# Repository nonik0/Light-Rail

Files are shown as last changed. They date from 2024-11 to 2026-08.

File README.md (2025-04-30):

# Light Rail

## Overview & Acknowledgements

GIF animation of the basic hardware demo

Light Rail is a minimalist, interactive PCB game that simulates trains traveling along tracks, picking up and delivering cargo from platforms. The track is composed of yellow LEDs arranged in lines, which illuminate sequentially to create the effect of trains moving along the tracks. Next to each of the eight forks and crosses in the track is a button to switch its state. The board also has a three-character seven-segment display for showing the game status and/or score and four more buttons underneath the track for gameplay control. Light Rail can be powered with two LIR2032 batteries or via USB.

I also want to acknowledge and thank [PCBWay](https://www.pcbway.com/) for their generous support of this project! Even before I had the initial idea, PCBWay had already reached out to me asking if I would like to collaborate on my next project. However, I didn't actually see the email until I started looking into how I wanted to manufacture prototypes for Light Rail. Just getting the email and seeing that others were liking my older projects gave me a big motivation boost to continue with this project, be creative, and make something of my own. Overall, my experience with PCBWay was great and I would definitely recommend checking them out for your own projects!

For more details about my design goals, process, and ordering and production experience with PCBWay, please see my full [project writeup](https://altonimb.us/light-rail/)!

### Work Left
- first working game prototype
- further game ideas and testing
- investigate CR2032 batteries in series

## Hardware
The hardware is designed in KiCad 8.0 and all design files are included in the [hardware/kicad8.0](hardware/kicad8.0) directory.

The main hardware components are:
- [ATMega32u4](https://www.microchip.com/en-us/product/atmega32u4) 8-bit MCU
- [IS31FL3731](https://www.lumissil.com/applications/industrial/appliance/major-appliances/range-hood/is31fl3731) matrix LED driver (charliplexing)
- [AS1115](https://ams-osram.com/products/drivers/led-drivers/ams-as1115-led-driver-ic) seven-segment LED display driver
- [KCSC02-105](https://www.kingbright.com/attachments/file/psearch/000/00/00/KCSC02-105(Ver.12A).pdf) seven-segment LED display
- [MIC5219](https://ww1.microchip.com/downloads/en/DeviceDoc/MIC5219-500mA-Peak-Output-LDO-Regulator-DS20006021A.pdf) 3.3V LDS Regulator
- Yellow "track" and red "platform" LEDs, 144 total

See the [Bill of Material (BoM)](hardware/documents/Light_Rail_BOM.xlsx) for complete list of components used and my [project writeup](WRITEUP.md) for more details.

## Firmware

The firmware initially started as a C++/PlatformIO project, which can be found in the [firmware/cpp](firmware/cpp) directory. Before I actually received the inital prototype boards I decided to pivot and write everything in Rust, which can be found in the [firmware/rust](firmware/rust) directory. As part of the effort to get back to where I left off with the C++ firmware, I did the following:
- Wrote a new [AS1115 driver](https://github.com/nonik0/as1115) (TODO: finish and polish design before publishing to crates.io)
- Wrote new tone library for avr-hal (TODO: integrate into avr-hal and open PR)
- Updated existing fork of [IS31FL3731](https://github.com/nonik0/is31fl3731) driver to latest embedded-hal with other minor additions

TODO: basic overview of game design and firmware components (in second writeup?)

## Images

#### Prototype
<p align="center" width="100%">
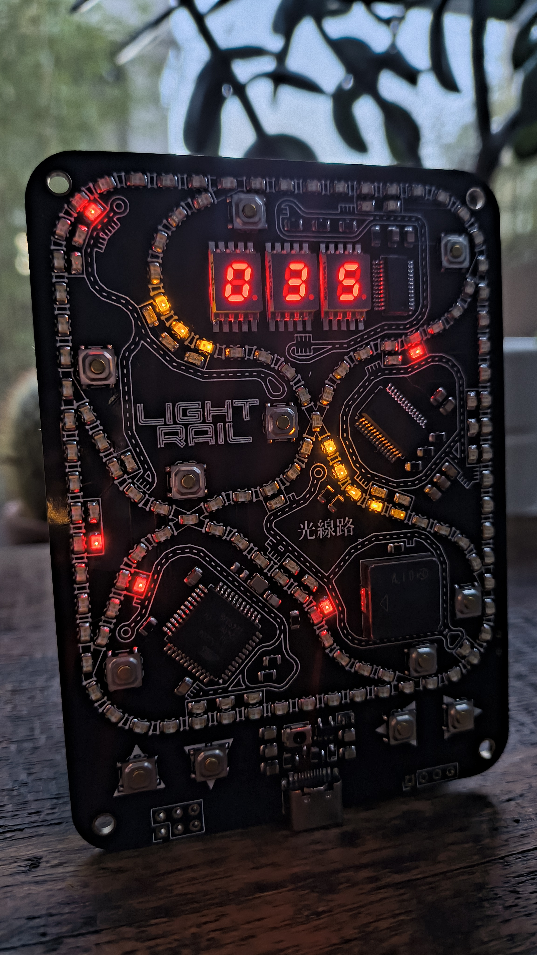
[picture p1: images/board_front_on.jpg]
  
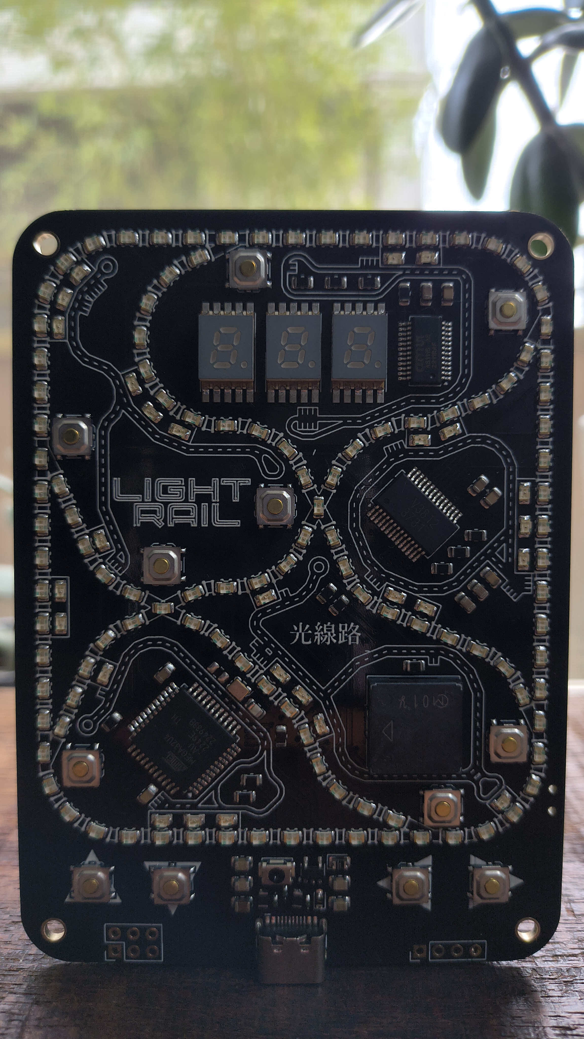
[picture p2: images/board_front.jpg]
  
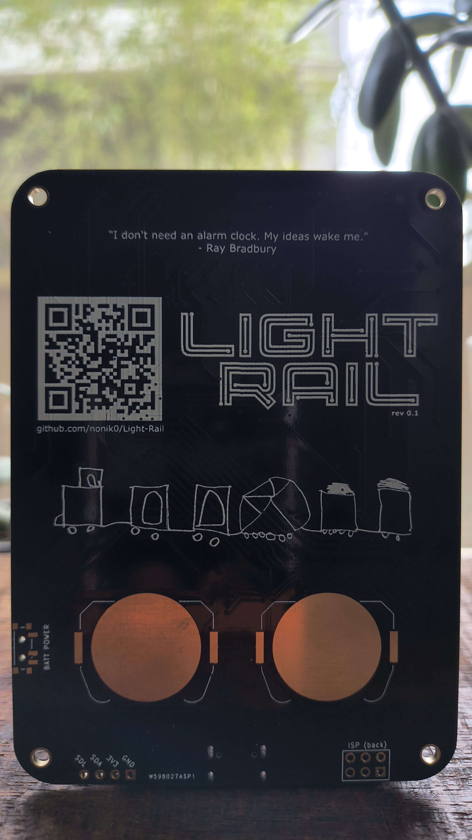
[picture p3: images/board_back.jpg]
  
</p>

#### Schematic
<p align="center" width="100%">
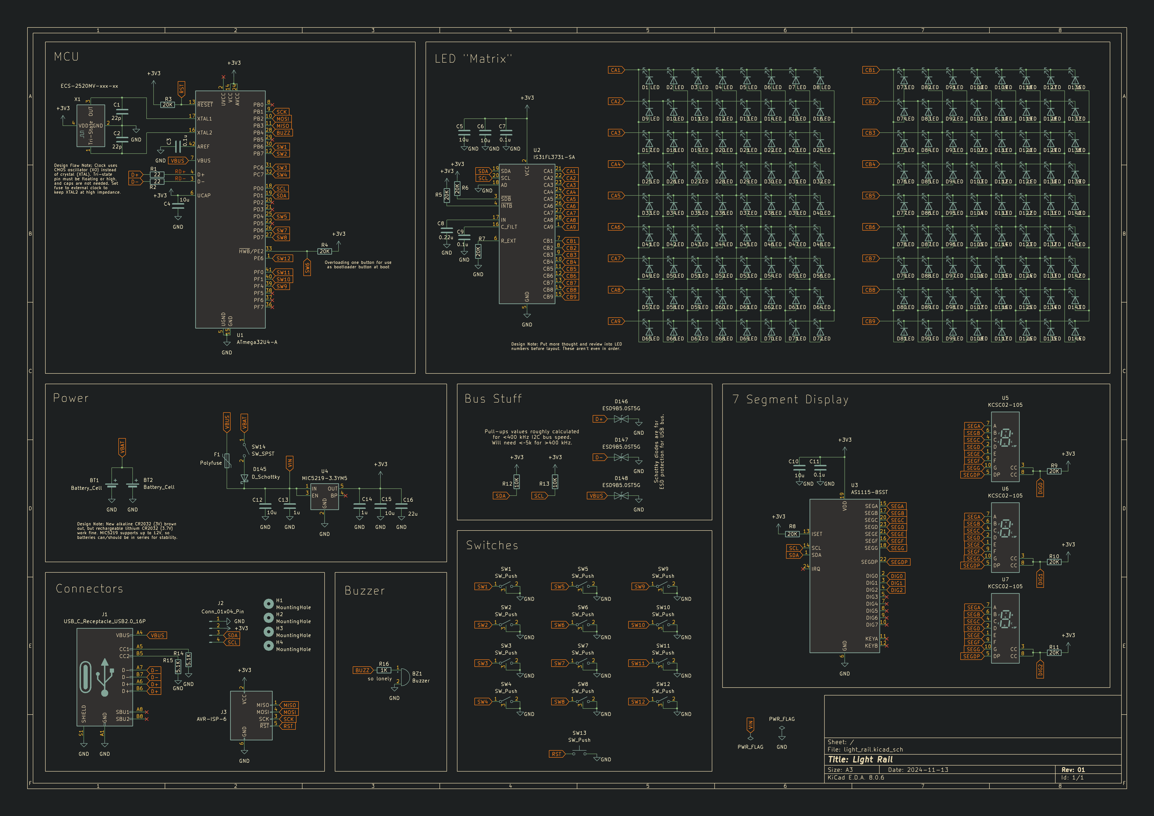
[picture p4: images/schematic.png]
  
</p>

#### PCB Layout
<p align="center" width="100%">
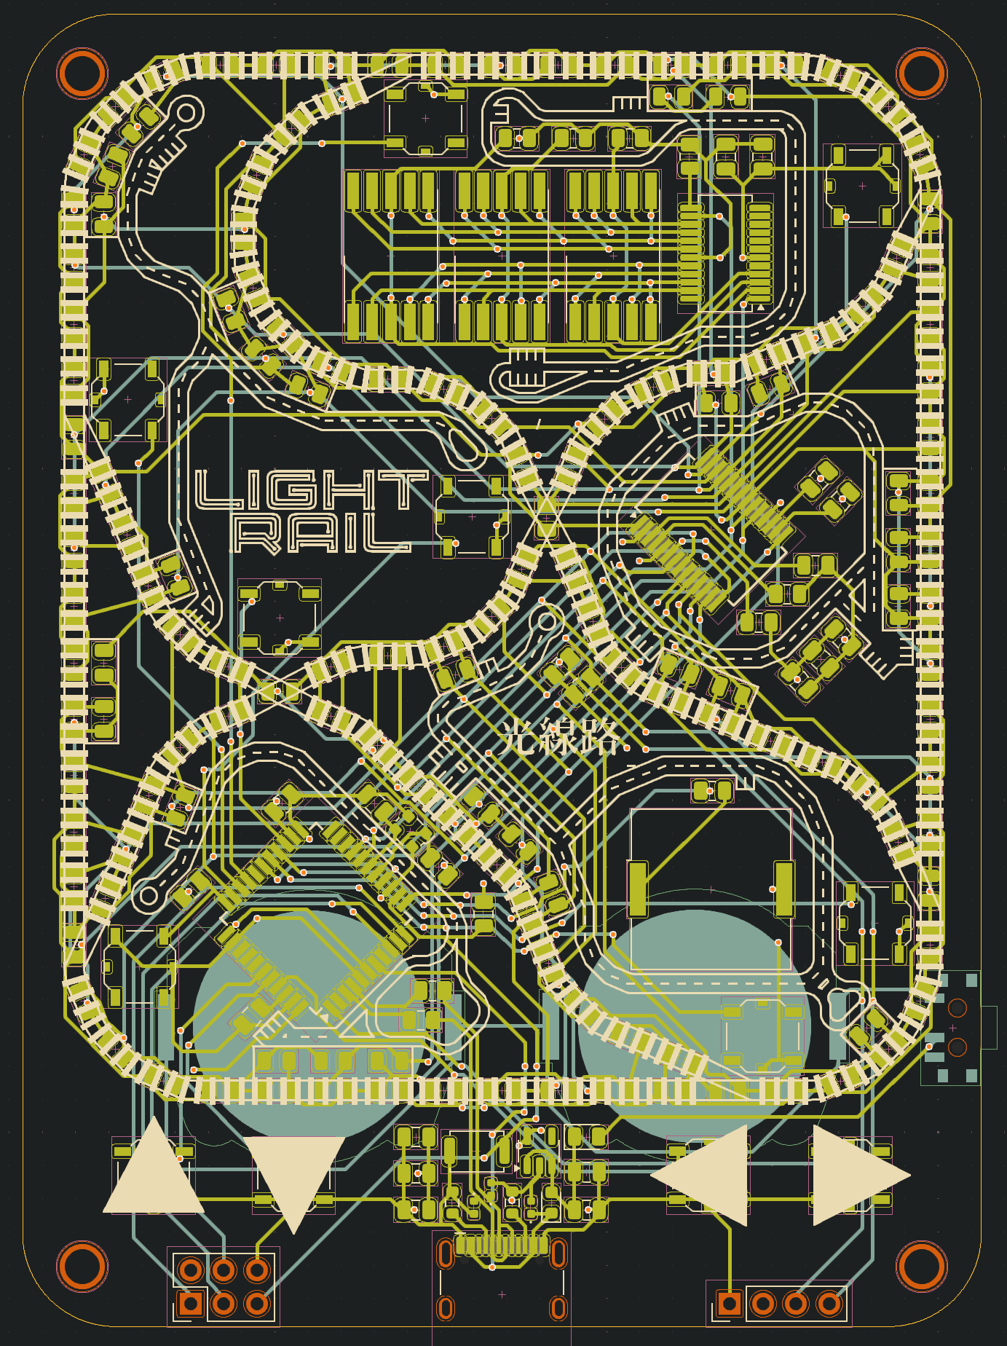
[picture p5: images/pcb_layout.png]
  
</p>

#### Render
<p align="center" width="100%">
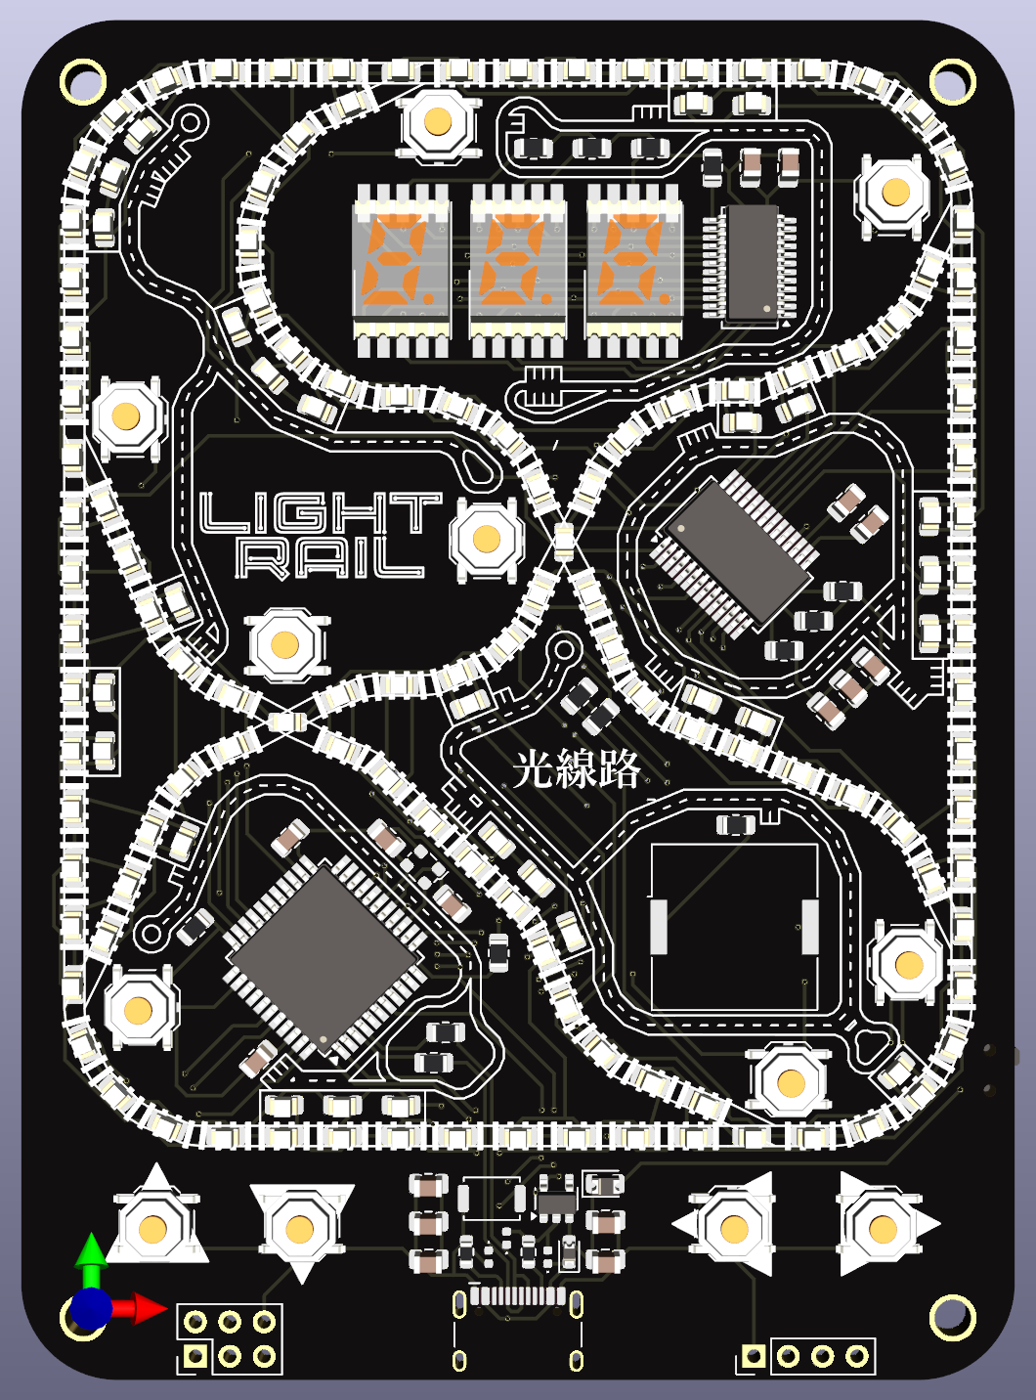
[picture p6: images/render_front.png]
  
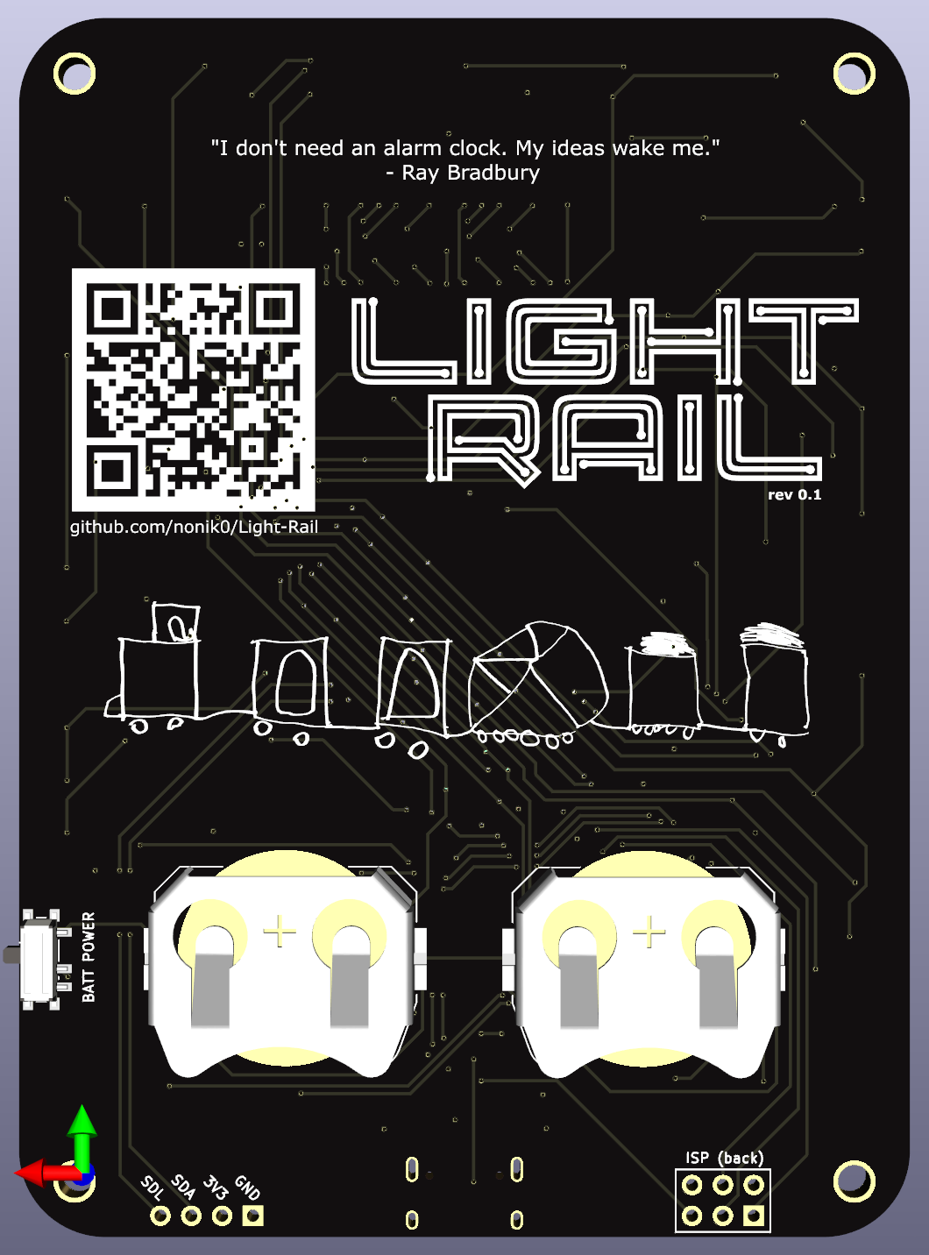
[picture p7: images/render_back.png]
  
</p>

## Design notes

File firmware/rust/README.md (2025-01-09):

light-rail
==========

Rust project for the _Arduino Leonardo_.

## Build Instructions
1. Install prerequisites as described in the [`avr-hal` README] (`avr-gcc`, `avr-libc`, `avrdude`, [`ravedude`]).

2. Run `cargo build` to build the firmware.

3. Run `cargo run` to flash the firmware to a connected board.  If `ravedude`
   fails to detect your board, check its documentation at
   <https://crates.io/crates/ravedude>.

4. `ravedude` will open a console session after flashing where you can interact
   with the UART console of your board.

[`avr-hal` README]: https://github.com/Rahix/avr-hal#readme
[`ravedude`]: https://crates.io/crates/ravedude

## License
Licensed under either of

 - Apache License, Version 2.0
   ([LICENSE-APACHE](LICENSE-APACHE) or <http://www.apache.org/licenses/LICENSE-2.0>)
 - MIT license
   ([LICENSE-MIT](LICENSE-MIT) or <http://opensource.org/licenses/MIT>)

at your option.

## Contribution
Unless you explicitly state otherwise, any contribution intentionally submitted
for inclusion in the work by you, as defined in the Apache-2.0 license, shall
be dual licensed as above, without any additional terms or conditions.

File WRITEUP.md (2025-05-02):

Moved [here](https://altonimb.us/light-rail/).

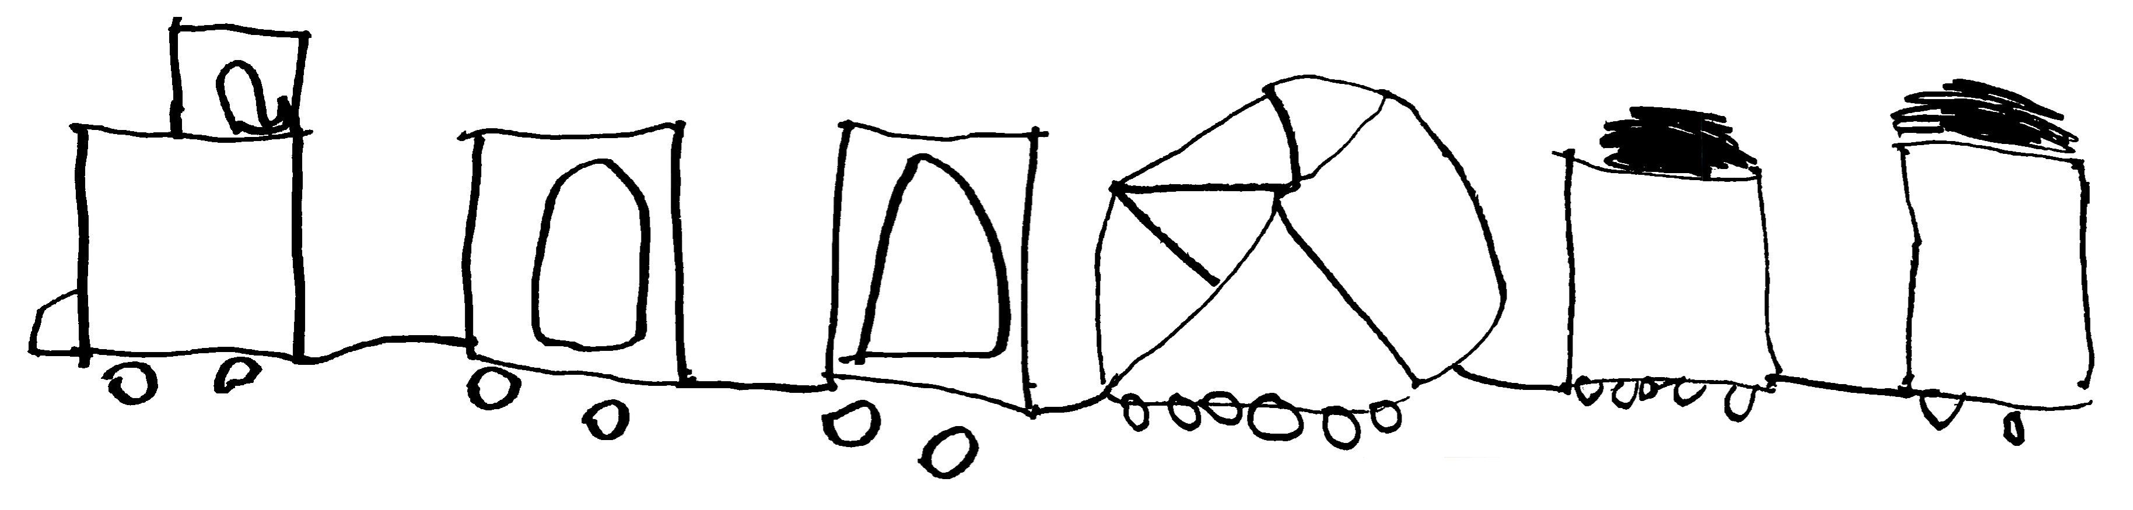
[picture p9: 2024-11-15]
images/train_drawing_long.png

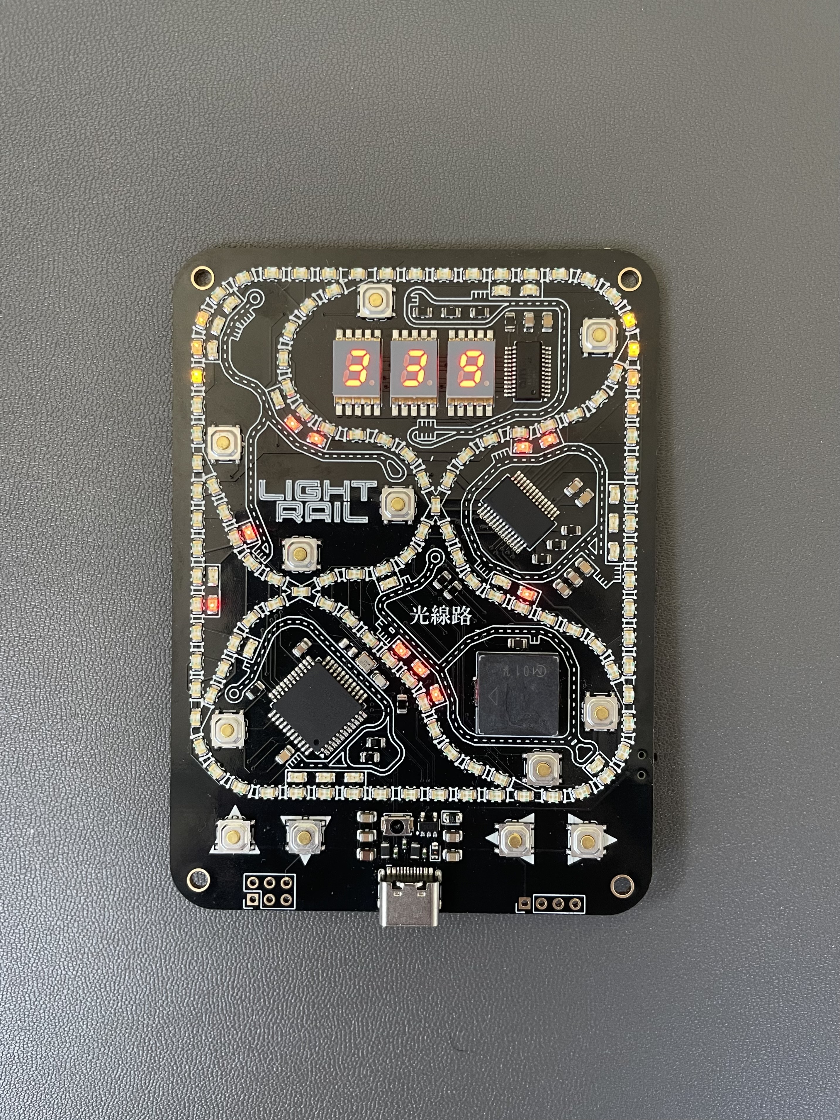
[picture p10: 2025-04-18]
images/board_front_2.jpeg

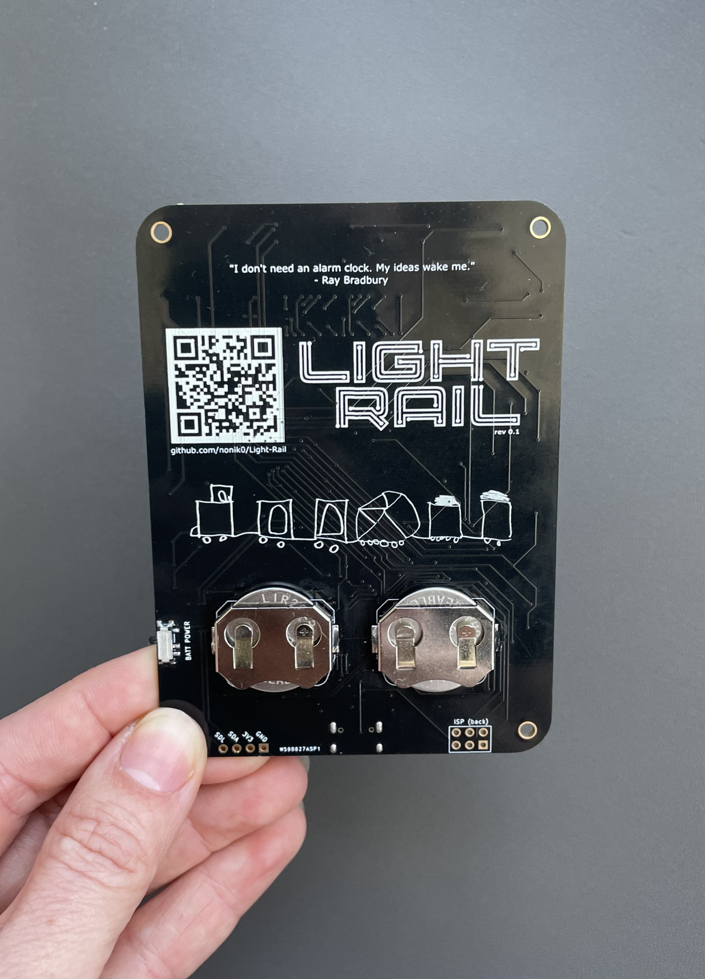
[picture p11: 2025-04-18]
images/board_back_2.jpg

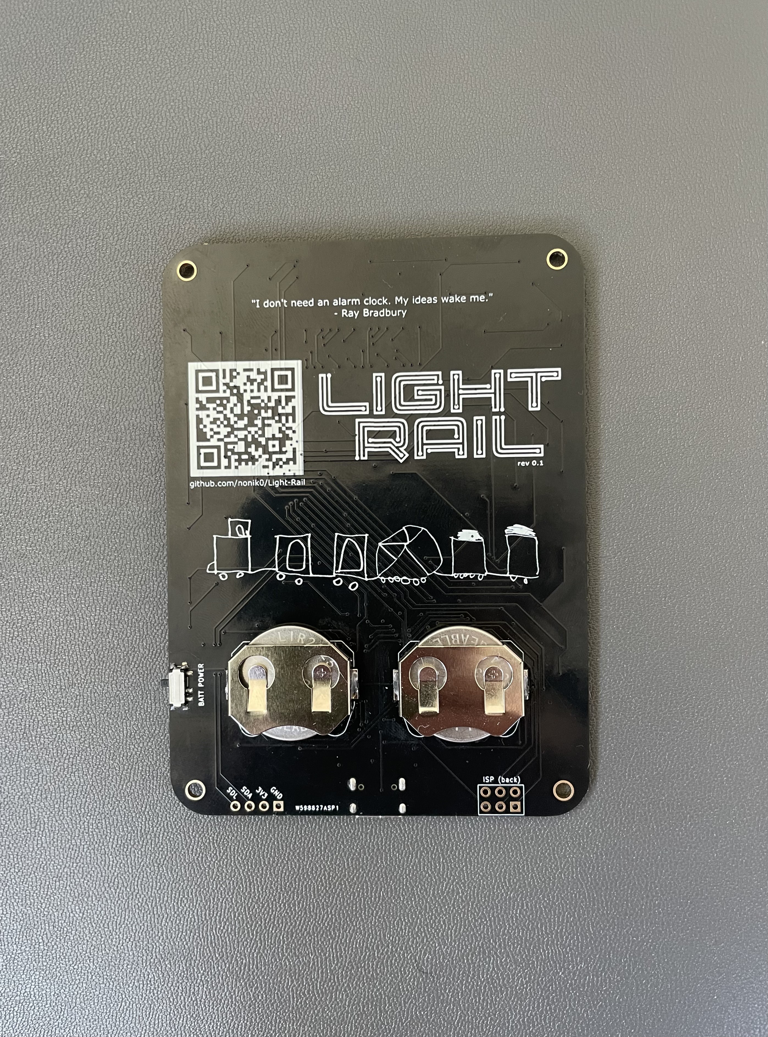
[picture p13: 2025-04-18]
images/board_back_3.jpeg

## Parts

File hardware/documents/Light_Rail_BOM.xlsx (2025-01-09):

 |  |  | T-P2W598827A BOM (Light Rail Bill of Materials)
Item # | *Designator | *Qty | Manufacturer | *Mfg Part # | Description / Value |  | Type | Your Instructions / Notes
1 | BZ1 | 1 | Murata Electronics | PKLCS1212E4001-R1 | BUZZER PIEZO 1.5V 12X12MM SMD | SMD Gull-wing lead | SMD | ask before substitute
2 | C1,C2 | 2 | Samsung Electro-Mechanics | CL21C220JBANFNC | CAP CER 22PF 50V C0G/NP0 0805 | 0805 | SMD | can substitute cheaper part
3 | C3,C7,C9,C11 | 4 | Samsung Electro-Mechanics | CL21B104KBCNNNC | CAP CER 0.1UF 50V X7R 0805 | 0805 | SMD | can substitute cheaper part
4 | C4-C6,C10,C12,C15 | 6 | Samsung Electro-Mechanics | CL21A106KOQNNNG | CAP CER 10UF 16V X5R 0805 | 0805 | SMD | can substitute cheaper part
5 | C8 | 1 | Samsung Electro-Mechanics | CL21B224KAFNFNE | CAP CER 0.22UF 25V X7R 0805 | 0805 | SMD | can substitute cheaper part
6 | C13,C14 | 2 | Samsung Electro-Mechanics | CL21B105KPFNNNE | CAP CER 1UF 10V X7R 0805 | 0805 | SMD | can substitute cheaper part
7 | C16 | 1 | Samsung Electro-Mechanics | CL21X226MRQNNNE | CAP CER 22UF 4V X6S 0805 | 0805 | SMD | can substitute cheaper part
8 | D1,D3-D5,D8-D11,D13,D15-D19,D21-D25,D27-D32,D35,D37-D46,D48-D57,D59-D61,D63-D70,D72-D74,D76,D77,D79-D88,D90,D91,D93,D95-D103,D105-D109,D113,D114,D117-D133,D135,D137-D144 | 117 | Lite-On Inc. | LTST-C170YKT | LED YELLOW CLEAR SMD | 0805 | SMD | can substitute cheaper part
9 | D2,D6,D7,D12,D14,D20,D26,D33,D34,D36,D47,D58,D62,D71,D75,D78,D89,D92,D94,D104,D110-112,D115,D116,D134,D136 | 27 | Lite-On Inc. | LTST-C171KRKT | LED RED CLEAR SMD | 0805 | SMD | can substitute cheaper part
10 | D145 | 1 | KYOCERA AVX | SD0805S020S1R0 | DIODE SCHOTTKY 20V 1A 0805 | 0805 | SMD | can substitute cheaper part
11 | D146-D148 | 3 | INPAQ Technology Co., Ltd | CES10402V05B0DG | ESD SUPPRESSORS 0402 VDC 5V CP 0 | 0402 | SMD | can substitute cheaper part
12 | F1 | 1 | YAGEO | SMD0603B035TF | PTC RESET FUSE 6V 350MA 0603 | 0603 | SMD | can substitute cheaper part
13 | J1 | 1 | GCT | USB4215-03-A | USB C Receptac, Sht Body, USB2.0 | 24 (16+8 Dummy) | SMD | can substitute cheaper part
14 | R1,R2 | 2 | Vishay Dale | CRCW080522R0JNEA | RES SMD 22 OHM 5% 1/8W 0805 | 0805 | SMD | can substitute cheaper part
15 | R3-R11 | 9 | Vishay Dale | CRCW080520K0FKEA | RES SMD 20K OHM 1% 1/8W 0805 | 0805 | SMD | can substitute cheaper part
16 | R12,R13 | 2 | Vishay Dale | CRCW080510K0FKEA | RES SMD 10K OHM 1% 1/8W 0805 | 0805 | SMD | can substitute cheaper part
17 | R14,R15 | 2 | Vishay Dale | CRCW08055K10JNEA | RES SMD 5.1K OHM 5% 1/8W 0805 | 0805 | SMD | can substitute cheaper part
18 | R16 | 1 | Vishay Dale | CRCW08051K00FKEA | RES SMD 1K OHM 1% 1/8W 0805 | 0805 | SMD | can substitute cheaper part
19 | SW1-SW12 | 13 | C&K | PTS526SMG15JSMTR2 LFS | SWITCH TACTILE SPST-NO 0.05A 12V | J Lead | SMD | ask before substitute
20 | SW13 | 1 | C&K | SKRKAGE020 | SWITCH TACTILE SPST-NO 0.05A 12V | SMD Tab | SMD | can substitute cheaper part
21 | U1 | 1 | Microchip Technology | ATMEGA32U4-AU | IC MCU 8BIT 32KB FLASH 44TQFP | 44-TQFP | SMD
22 | U2 | 1 | Lumissil Microsystems | IS31FL3731-SALS2-TR | IC LED DRV LIN ANALOG 28SSOP | 28-SSOP | SMD
23 | U3 | 1 | ams-OSRAM USA INC. | AS1115BSST | IC DRVR 64 LED 7SEG 8 DGT 24QSOP | 24-QSOP | SMD | ask before substitute
24 | U4 | 1 | Microchip Technology | MIC5219-3.3YM5-TR | IC REG LINEAR 3.3V 500MA SOT23-5 | SOT-23-5 | SMD
25 | U5,U6,U7 | 3 | Kingbright | ACSC02-41SURKWA-F01 | DISPLAY 7-SEG 0.2" SGL RED 10SMD | 10-SMD | SMD | ask before substitute
26 | X1 | 1 | ECS Inc. | ECS-2033-080-BN | XTAL OSC XO 8.0000MHZ CMOS SMD | 4-SMD | SMD | can substitute cheaper part
27 | J2,J3 | N/A | N/A | N/A | N/A | N/A | N/A | not assembling
28 | BT1,BT2 | 2 | N/A | N/A | N/A | N/A | N/A | not assembling
29 | SW14 | 1 | N/A | N/A | N/A | N/A | N/A | not assembling

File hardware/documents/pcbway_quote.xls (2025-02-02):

PCBWay Bom Quotation, Product No.:T-P2W598827A
Item # | *Designator | *Qty | Manufacturer | *Mfg Part # | Description / Value | *Package/Footprint | Mounting Type | Your Instructions / Notes | *Unit Price(5 sets) | *Total | *Delivery Time | *Actual Purchase Mfg Part # | *PCBWay Note | Customer Reply
1 | BZ1 | 1 | Murata Electronics | PKLCS1212E4001-R1 | BUZZER PIEZO 1.5V 12X12MM SMD | SMD Gull-wing lead | SMD | ask before substitute | $0.916 | $4.580
2 | C1,C2 | 2 | Samsung Electro-Mechanics | CL21C220JBANFNC | CAP CER 22PF 50V C0G/NP0 0805 | 0805 | SMD | can substitute cheaper part | $0.050 | $0.500
3 | C3,C7,C9,C11 | 4 | Samsung Electro-Mechanics | CL21B104KBCNNNC | CAP CER 0.1UF 50V X7R 0805 | 0805 | SMD | can substitute cheaper part | $0.050 | $1.000
4 | C4-C6,C10,C12,C15 | 6 | Samsung Electro-Mechanics | CL21A106KOQNNNG | CAP CER 10UF 16V X5R 0805 | 0805 | SMD | can substitute cheaper part | $0.042 | $1.260
5 | C8 | 1 | Samsung Electro-Mechanics | CL21B224KAFNFNE | CAP CER 0.22UF 25V X7R 0805 | 0805 | SMD | can substitute cheaper part | $0.105 | $0.525
6 | C13,C14 | 2 | Samsung Electro-Mechanics | CL21B105KPFNNNE | CAP CER 1UF 10V X7R 0805 | 0805 | SMD | can substitute cheaper part | $0.050 | $0.500
7 | C16 | 1 | Samsung Electro-Mechanics | CL21X226MRQNNNE | CAP CER 22UF 4V X6S 0805 | 0805 | SMD | can substitute cheaper part | $0.063 | $0.315
8 | D1,D3-D5,D8-D11,D13,D15-D19,D21-D25,D27-D32,D35,D37-D46,D48-D57,D59-D61,D63-D70,D72-D74,D76,D77,D79-D88,D90,D91,D93,D95-D103,D105-D109,D113,D114,D117-D133,D135,D137-D144 | 117 | Lite-On Inc. | LTST-C170YKT | LED YELLOW CLEAR SMD | 0805 | SMD | can substitute cheaper part | $0.031 | $18.135
9 | D2,D6,D7,D12,D14,D20,D26,D33,D34,D36,D47,D58,D62,D71,D75,D78,D89,D92,D94,D104,D110-112,D115,D116,D134,D136 | 27 | Lite-On Inc. | LTST-C171KRKT | LED RED CLEAR SMD | 0805 | SMD | can substitute cheaper part | $0.031 | $4.185
10 | D145 | 1 | KYOCERA AVX | SD0805S020S1R0 | DIODE SCHOTTKY 20V 1A 0805 | 0805 | SMD | can substitute cheaper part | $0.431 | $2.155
11 | D146-D148 | 3 | INPAQ Technology Co., Ltd | CES10402V05B0DG | ESD SUPPRESSORS 0402 VDC 5V CP 0 | 0402 | SMD | can substitute cheaper part | $0.085 | $1.275 | 7-10 Workdays
12 | F1 | 1 | YAGEO | SMD0603B035TF | PTC RESET FUSE 6V 350MA 0603 | 0603 | SMD | can substitute cheaper part | $0.320 | $1.600 | 7-10 Workdays
13 | J1 | 1 | GCT | USB4215-03-A | USB C Receptac, Sht Body, USB2.0 | 24 (16+8 Dummy) | SMD | can substitute cheaper part | $0.675 | $3.375 | 7-10 Workdays
14 | R1,R2 | 2 | Vishay Dale | CRCW080522R0JNEA | RES SMD 22 OHM 5% 1/8W 0805 | 0805 | SMD | can substitute cheaper part | $0.092 | $0.920
15 | R3-R11 | 9 | Vishay Dale | CRCW080520K0FKEA | RES SMD 20K OHM 1% 1/8W 0805 | 0805 | SMD | can substitute cheaper part | $0.023 | $1.035
16 | R12,R13 | 2 | Vishay Dale | CRCW080510K0FKEA | RES SMD 10K OHM 1% 1/8W 0805 | 0805 | SMD | can substitute cheaper part | $0.092 | $0.920
17 | R14,R15 | 2 | Vishay Dale | CRCW08055K10JNEA | RES SMD 5.1K OHM 5% 1/8W 0805 | 0805 | SMD | can substitute cheaper part | $0.092 | $0.920
18 | R16 | 1 | Vishay Dale | CRCW08051K00FKEA | RES SMD 1K OHM 1% 1/8W 0805 | 0805 | SMD | can substitute cheaper part | $0.092 | $0.460
19 | SW1-SW12 | 12 | C&K | PTS526SMG15JSMTR2 LFS | SWITCH TACTILE SPST-NO 0.05A 12V | J Lead | SMD | ask before substitute | $0.185 | $11.100 | 7-10 Workdays
20 | S13 | 1 | C&K | PTS810SJS250SMTR LFS | SWITCH TACTILE SPST-NO 0.05A 16V | J Lead | SMD | can substitute cheaper part | $0.559 | $2.795 | 7-10 Workdays
21 | U1 | 1 | Microchip Technology | ATMEGA32U4-AU | IC MCU 8BIT 32KB FLASH 44TQFP | 44-TQFP | SMD |  | $5.132 | $25.660
22 | U2 | 1 | Lumissil Microsystems | IS31FL3731-SALS2-TR | IC LED DRV LIN ANALOG 28SSOP | 28-SSOP | SMD |  | $1.175 | $5.875
23 | U3 | 1 | ams-OSRAM USA INC. | AS1115BSST | IC DRVR 64 LED 7SEG 8 DGT 24QSOP | 24-QSOP | SMD | ask before substitute | $4.487 | $22.435 | 7-10 Workdays | AS1115-BSST
24 | U4 | 1 | Microchip Technology | MIC5219-3.3YM5-TR | IC REG LINEAR 3.3V 500MA SOT23-5 | SOT-23-5 | SMD
25 | U5,U6,U7 | 3 | Kingbright | ACSC02-41SURKWA-F01 | DISPLAY 7-SEG 0.2 SGL RED 10SMD | 10-SMD | SMD | ask before substitute | $2.426 | $36.390
26 | X1 | 1 | ECS Inc. | ECS-2033-080-BN | XTAL OSC XO 8.0000MHZ CMOS SMD | 4-SMD | SMD | can substitute cheaper part | $1.318 | $6.590 | 7-10 Workdays
27 | J2,J3 | 0 | N/A | N/A | N/A | N/A | N/A | not assembling |  |  |  |  | [DNP不要贴];
28 | BT1,BT2 | 2 | N/A | N/A | N/A | N/A | N/A | not assembling |  |  |  |  | [DNP不要贴];
29 | SW14 | 1 | N/A | N/A | N/A | N/A | N/A | not assembling |  |  |  |  | [DNP不要贴];
 |  |  |  |  |  |  |  |  | Component Cost | $154.50
 |  |  |  |  |  |  |  |  | Assembly Cost | $255.00
 |  |  |  |  |  |  |  |  | PCB Cost | $96.54
 |  |  |  |  |  |  |  |  | All Total 5 Sets | $506.05

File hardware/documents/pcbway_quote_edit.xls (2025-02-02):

PCBWay Bom Quotation, Product No.:T-P2W598827A
Item # | *Designator | *Qty | Manufacturer | *Mfg Part # | Description / Value | *Package/Footprint | Mounting Type | Your Instructions / Notes | *Unit Price(5 sets) | *Total | *Unit Price(100 sets) | Total (100) | *Delivery Time | *Actual Purchase Mfg Part # | *PCBWay Note | Customer Reply
1 | BZ1 | 1 | Murata Electronics | PKLCS1212E4001-R1 | BUZZER PIEZO 1.5V 12X12MM SMD | SMD Gull-wing lead | SMD | ask before substitute | $0.916 | $4.580 | $0.718 | $71.800
2 | C1,C2 | 2 | Samsung Electro-Mechanics | CL21C220JBANFNC | CAP CER 22PF 50V C0G/NP0 0805 | 0805 | SMD | can substitute cheaper part | $0.050 | $0.500 | $0.018 | $3.600
3 | C3,C7,C9,C11 | 4 | Samsung Electro-Mechanics | CL21B104KBCNNNC | CAP CER 0.1UF 50V X7R 0805 | 0805 | SMD | can substitute cheaper part | $0.050 | $1.000 | $0.011 | $4.400
4 | C4-C6,C10,C12,C15 | 6 | Samsung Electro-Mechanics | CL21A106KOQNNNG | CAP CER 10UF 16V X5R 0805 | 0805 | SMD | can substitute cheaper part | $0.042 | $1.260 | $0.017 | $10.200
5 | C8 | 1 | Samsung Electro-Mechanics | CL21B224KAFNFNE | CAP CER 0.22UF 25V X7R 0805 | 0805 | SMD | can substitute cheaper part | $0.105 | $0.525 | $0.023 | $2.300
6 | C13,C14 | 2 | Samsung Electro-Mechanics | CL21B105KPFNNNE | CAP CER 1UF 10V X7R 0805 | 0805 | SMD | can substitute cheaper part | $0.050 | $0.500 | $0.017 | $3.400
7 | C16 | 1 | Samsung Electro-Mechanics | CL21X226MRQNNNE | CAP CER 22UF 4V X6S 0805 | 0805 | SMD | can substitute cheaper part | $0.063 | $0.315 | $0.063 | $6.300
8 | D1,D3-D5,D8-D11,D13,D15-D19,D21-D25,D27-D32,D35,D37-D46,D48-D57,D59-D61,D63-D70,D72-D74,D76,D77,D79-D88,D90,D91,D93,D95-D103,D105-D109,D113,D114,D117-D133,D135,D137-D144 | 117 | Lite-On Inc. | LTST-C170YKT | LED YELLOW CLEAR SMD | 0805 | SMD | can substitute cheaper part | $0.031 | $18.135 | $0.031 | $362.700
9 | D2,D6,D7,D12,D14,D20,D26,D33,D34,D36,D47,D58,D62,D71,D75,D78,D89,D92,D94,D104,D110-112,D115,D116,D134,D136 | 27 | Lite-On Inc. | LTST-C171KRKT | LED RED CLEAR SMD | 0805 | SMD | can substitute cheaper part | $0.031 | $4.185 | $0.031 | $83.700
10 | D145 | 1 | KYOCERA AVX | SD0805S020S1R0 | DIODE SCHOTTKY 20V 1A 0805 | 0805 | SMD | can substitute cheaper part | $0.431 | $2.155 | $0.180 | $18.000
11 | D146-D148 | 3 | INPAQ Technology Co., Ltd | CES10402V05B0DG | ESD SUPPRESSORS 0402 VDC 5V CP 0 | 0402 | SMD | can substitute cheaper part | $0.085 | $1.275 | $0.038 | $11.400 | 7-10 Workdays
12 | F1 | 1 | YAGEO | SMD0603B035TF | PTC RESET FUSE 6V 350MA 0603 | 0603 | SMD | can substitute cheaper part | $0.320 | $1.600 | $0.123 | $12.300 | 7-10 Workdays
13 | J1 | 1 | GCT | USB4215-03-A | USB C Receptac, Sht Body, USB2.0 | 24 (16+8 Dummy) | SMD | can substitute cheaper part | $0.675 | $3.375 | $0.424 | $42.400 | 7-10 Workdays
14 | R1,R2 | 2 | Vishay Dale | CRCW080522R0JNEA | RES SMD 22 OHM 5% 1/8W 0805 | 0805 | SMD | can substitute cheaper part | $0.092 | $0.920 | $0.012 | $2.400
15 | R3-R11 | 9 | Vishay Dale | CRCW080520K0FKEA | RES SMD 20K OHM 1% 1/8W 0805 | 0805 | SMD | can substitute cheaper part | $0.023 | $1.035 | $0.015 | $13.500
16 | R12,R13 | 2 | Vishay Dale | CRCW080510K0FKEA | RES SMD 10K OHM 1% 1/8W 0805 | 0805 | SMD | can substitute cheaper part | $0.092 | $0.920 | $0.014 | $2.800
17 | R14,R15 | 2 | Vishay Dale | CRCW08055K10JNEA | RES SMD 5.1K OHM 5% 1/8W 0805 | 0805 | SMD | can substitute cheaper part | $0.092 | $0.920 | $0.014 | $2.800
18 | R16 | 1 | Vishay Dale | CRCW08051K00FKEA | RES SMD 1K OHM 1% 1/8W 0805 | 0805 | SMD | can substitute cheaper part | $0.092 | $0.460 | $0.015 | $1.500
19 | SW1-SW12 | 12 | C&K | PTS526SMG15JSMTR2 LFS | SWITCH TACTILE SPST-NO 0.05A 12V | J Lead | SMD | ask before substitute | $0.185 | $11.100 | $0.086 | $103.200 | cheapest option for small/flat?
20 | S13 | 1 | C&K | PTS810SJS250SMTR LFS | SWITCH TACTILE SPST-NO 0.05A 16V | J Lead | SMD | can substitute cheaper part | $0.559 | $2.795 | $0.333 | $33.300 | 7-10 Workdays
21 | U1 | 1 | Microchip Technology | ATMEGA32U4-AU | IC MCU 8BIT 32KB FLASH 44TQFP | 44-TQFP | SMD |  | $5.132 | $25.660 | $4.390 | $439.000
22 | U2 | 1 | Lumissil Microsystems | IS31FL3731-SALS2-TR | IC LED DRV LIN ANALOG 28SSOP | 28-SSOP | SMD |  | $1.175 | $5.875 | $1.140 | $114.000
23 | U3 | 1 | ams-OSRAM USA INC. | AS1115BSST | IC DRVR 64 LED 7SEG 8 DGT 24QSOP | 24-QSOP | SMD | ask before substitute | $4.487 | $22.435 | $1.890 | $189.000 | 7-10 Workdays | AS1115-BSST
24 | U4 | 1 | Microchip Technology | MIC5219-3.3YM5-TR | IC REG LINEAR 3.3V 500MA SOT23-5 | SOT-23-5 | SMD |  |  |  | $0.900 | $90.000
25 | U5,U6,U7 | 3 | Kingbright | ACSC02-41SURKWA-F01 | DISPLAY 7-SEG 0.2 SGL RED 10SMD | 10-SMD | SMD | ask before substitute | $2.426 | $36.390 | $1.630 | $489.000
26 | X1 | 1 | ECS Inc. | ECS-2033-080-BN | XTAL OSC XO 8.0000MHZ CMOS SMD | 4-SMD | SMD | can substitute cheaper part | $1.318 | $6.590 | $0.770 | $77.000 | 7-10 Workdays
27 | J2,J3 | 0 | N/A | N/A | N/A | N/A | N/A | not assembling |  |  |  |  |  |  | [DNP不要贴];
28 | BT1,BT2 | 2 | N/A | N/A | N/A | N/A | N/A | not assembling |  |  |  |  |  |  | [DNP不要贴];
29 | SW14 | 1 | N/A | N/A | N/A | N/A | N/A | not assembling |  |  |  |  |  |  | [DNP不要贴];
 |  |  |  |  |  |  |  |  | Component Cost | $154.50 | Component Cost | $2190.00
 |  |  |  |  |  |  |  |  | Assembly Cost | $255.00 | Assembly Cost | ??
 |  |  |  |  |  |  |  |  | PCB Cost | $96.54 | PCB Cost | ??
 |  |  |  |  |  |  |  |  | All Total 5 Sets | $506.05 | All Total 5 Sets | $2190.00

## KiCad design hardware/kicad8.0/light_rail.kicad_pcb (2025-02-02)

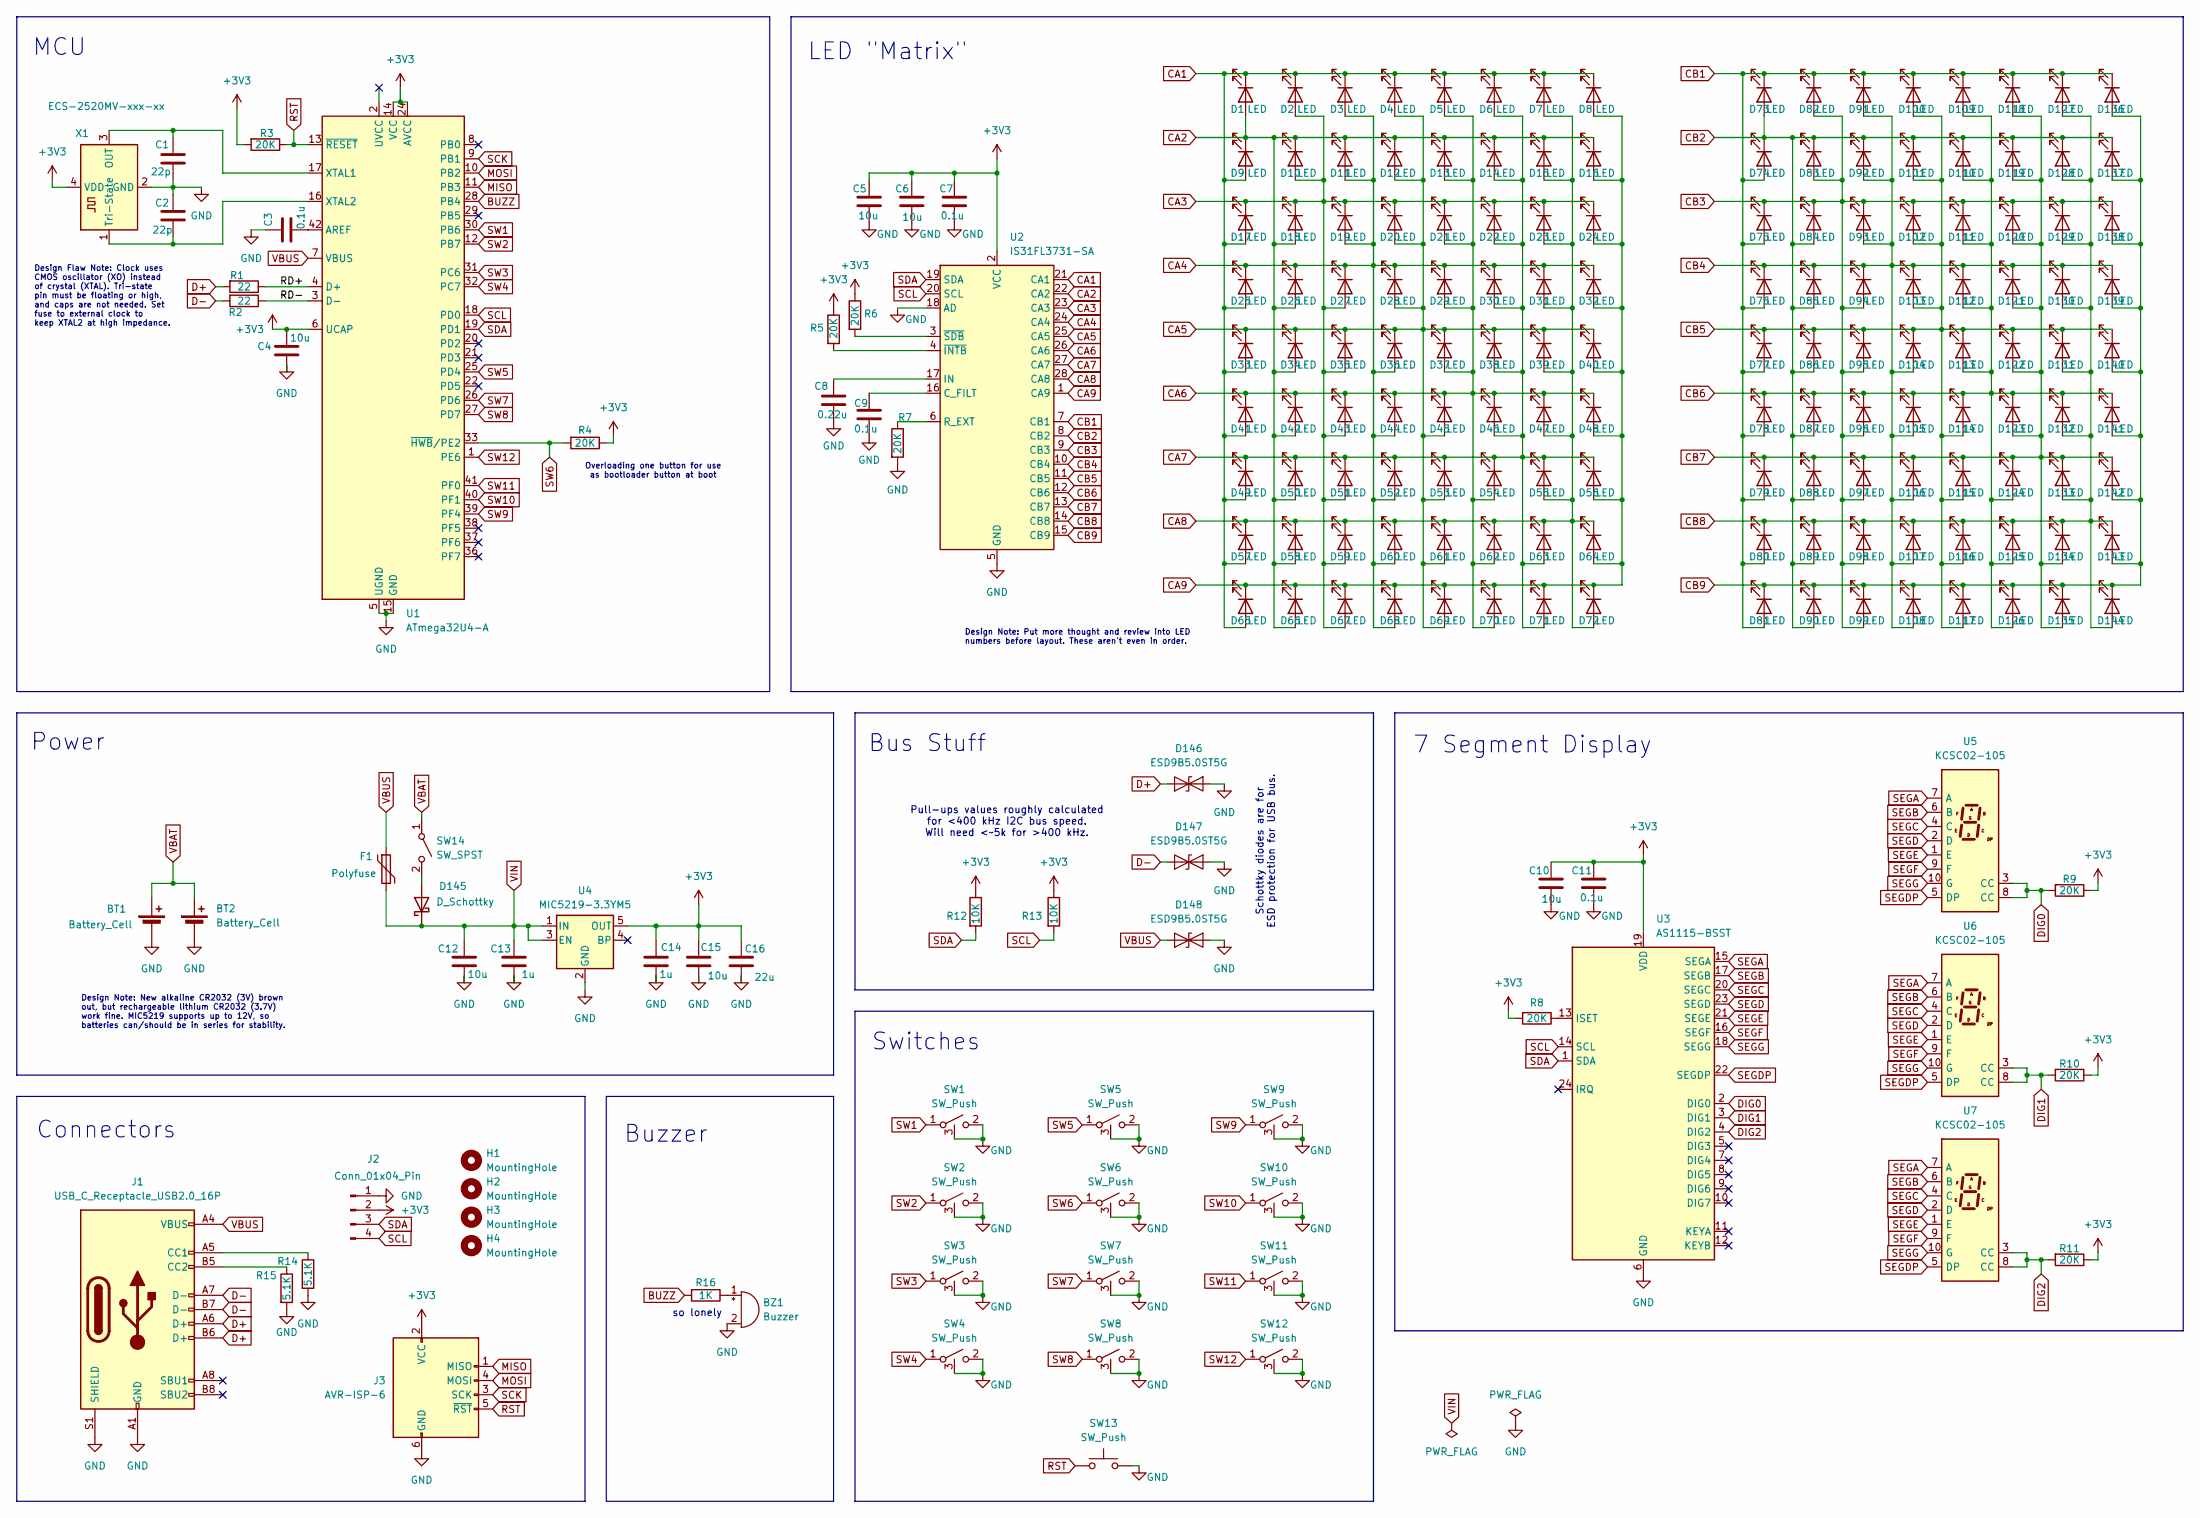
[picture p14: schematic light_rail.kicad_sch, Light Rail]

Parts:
BT1, BT2: Battery_Cell; BatteryHolder_Keystone_3034_1x20mm
BZ1: Buzzer; Buzzer_Murata_PKLCS1212E
C1, C2: 22p; C_0805_2012Metric
C3, C7, C9, C11: 0.1u; C_0805_2012Metric
C4, C5, C6, C10, C12, C15: 10u; C_0805_2012Metric
C8: 0.22u; C_0805_2012Metric
C13, C14: 1u; C_0805_2012Metric
C16: 22u; C_0805_2012Metric
D1, D9, D10, D16, D17, D18, D19, D21, D23, D27, D28, D32, D39, D41, D43, D48, D49, D50, D53, D54, D57, D59, D60, D61, D63, D64, D66, D68, D69, D70, D76, D85, D86, D88, D96, D97, D100, D101, D103, D105, D106, D108, D114, D117, D118, D121, D122, D123, D124, D125, D128, D132, D135, D137, D139, D140, D141, D143: LED; LED_0805_TrainTrack
D2, D6, D7, D12, D14, D20, D26, D33, D34, D36, D47, D58, D62, D71, D75, D78, D89, D92, D94, D104, D110, D111, D112, D115, D116, D134, D136: LED; LED_0805_NoSilkscreen
D3, D11, D38, D46, D67: LED; LED_0805_TrainTrackBendStart3
D4, D35, D72, D90, D91, D99, D102, D109, D127, D142: LED; LED_0805_TrainTrackBendStart4
D5, D13, D15, D22, D25, D37, D42, D44, D45, D79, D82, D83, D84, D120, D133, D138, D144: LED; LED_0805_TrainTrackBend1
D8, D30, D52, D56, D65, D74, D77, D98, D129, D130: LED; LED_0805_TrainTrackBend2
D24, D40, D51, D55, D73, D93, D126, D131: LED; LED_0805_TrainTrackEmpty
D29: LED; LED_0805_TrainTrackInnerBend2
D31, D80, D87: LED; LED_0805_TrainTrackBendStart2
D81, D95, D107, D119: LED; LED_0805_TrainTrackBendStart1
D113: LED; LED_0805_TrainTrackInnerBend1
D145: D_Schottky; D_0805_2012Metric
D146, D147, D148: ESD9B5.0ST5G; D_0402_1005Metric
F1: Polyfuse; D_0603_1608Metric
H1, H2, H3, H4: MountingHole; MountingHole_Custom
J1: USB_C_Receptacle_USB2.0_16P; USB_C_Receptacle_HCTL_HC-TYPE-C-16P-01A
J2: Conn_01x04_Pin; PinHeader_1x04_P2.54mm_Vertical
J3: AVR-ISP-6; PinHeader_2x03_P2.54mm_Vertical
R1, R2: 22; R_0805_2012Metric
R3, R4, R5, R6, R7, R8, R9, R10, R11: 20K; R_0805_2012Metric
R12, R13: 10K; R_0805_2012Metric
R14, R15: 5.1K; R_0603_1608Metric
R16: 1K; R_0805_2012Metric
SW1, SW2, SW3, SW4, SW5, SW6, SW7, SW8, SW9, SW10, SW11, SW12: SW_Push; SW_SPST_PTS526_JLeadsWGndPin
SW13: SW_Push; SW_Push_SPST_NO_Alps_SKRK
SW14: SW_SPST; SW_SPDT_PCM12
U1: ATmega32U4-A; TQFP-44_10x10mm_P0.8mm
U2: IS31FL3731-SA; SSOP-28_5.3x10.2mm_P0.65mm
U3: AS1115-BSST; QSOP-24_3.9x8.7mm_P0.635mm
U4: MIC5219-3.3YM5; SOT-23-5
U5, U6, U7: KCSC02-105
X1: ECS-2520MV-xxx-xx; Oscillator_SMD_ECS_2520MV-xxx-xx-4Pin_2.5x2.0mm

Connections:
+3V3: C4.1, C5.1, C6.1, C7.1, C10.1, C11.1, C14.1, C15.1, C16.1, J2.2, J3.2 (VCC), R3.2, R4.1, R5.1, R6.1, R8.2, R9.1, R10.1, R11.1, R12.1, R13.1, U1.6 (UCAP), U1.14 (VCC), U1.24 (AVCC), U1.34 (VCC), U1.44 (AVCC), U2.2 (VCC), U3.19 (VDD), U4.5 (OUT), X1.4 (VDD)
/RD+: R1.1, U1.4 (D+)
/RD-: R2.1, U1.3 (D-)
BUZZ: R16.2, U1.28 (PB4)
CA1: D1.1 (K), D2.1 (K), D3.1 (K), D4.1 (K), D5.1 (K), D6.1 (K), D7.1 (K), D8.1 (K), D9.2 (A), D17.2 (A), D25.2 (A), D33.2 (A), D41.2 (A), D49.2 (A), D57.2 (A), D65.2 (A), U2.21 (CA1)
CA2: D1.2 (A), D9.1 (K), D10.1 (K), D11.1 (K), D12.1 (K), D13.1 (K), D14.1 (K), D15.1 (K), D16.1 (K), D18.2 (A), D26.2 (A), D34.2 (A), D42.2 (A), D50.2 (A), D58.2 (A), D66.2 (A), U2.22 (CA2)
CA3: D2.2 (A), D10.2 (A), D17.1 (K), D18.1 (K), D19.1 (K), D20.1 (K), D21.1 (K), D22.1 (K), D23.1 (K), D24.1 (K), D27.2 (A), D35.2 (A), D43.2 (A), D51.2 (A), D59.2 (A), D67.2 (A), U2.23 (CA3)
CA4: D3.2 (A), D11.2 (A), D19.2 (A), D25.1 (K), D26.1 (K), D27.1 (K), D28.1 (K), D29.1 (K), D30.1 (K), D31.1 (K), D32.1 (K), D36.2 (A), D44.2 (A), D52.2 (A), D60.2 (A), D68.2 (A), U2.24 (CA4)
CA5: D4.2 (A), D12.2 (A), D20.2 (A), D28.2 (A), D33.1 (K), D34.1 (K), D35.1 (K), D36.1 (K), D37.1 (K), D38.1 (K), D39.1 (K), D40.1 (K), D45.2 (A), D53.2 (A), D61.2 (A), D69.2 (A), U2.25 (CA5)
CA6: D5.2 (A), D13.2 (A), D21.2 (A), D29.2 (A), D37.2 (A), D41.1 (K), D42.1 (K), D43.1 (K), D44.1 (K), D45.1 (K), D46.1 (K), D47.1 (K), D48.1 (K), D54.2 (A), D62.2 (A), D70.2 (A), U2.26 (CA6)
CA7: D6.2 (A), D14.2 (A), D22.2 (A), D30.2 (A), D38.2 (A), D46.2 (A), D49.1 (K), D50.1 (K), D51.1 (K), D52.1 (K), D53.1 (K), D54.1 (K), D55.1 (K), D56.1 (K), D63.2 (A), D71.2 (A), U2.27 (CA7)
CA8: D7.2 (A), D15.2 (A), D23.2 (A), D31.2 (A), D39.2 (A), D47.2 (A), D55.2 (A), D57.1 (K), D58.1 (K), D59.1 (K), D60.1 (K), D61.1 (K), D62.1 (K), D63.1 (K), D64.1 (K), D72.2 (A), U2.28 (CA8)
CA9: D8.2 (A), D16.2 (A), D24.2 (A), D32.2 (A), D40.2 (A), D48.2 (A), D56.2 (A), D64.2 (A), D65.1 (K), D66.1 (K), D67.1 (K), D68.1 (K), D69.1 (K), D70.1 (K), D71.1 (K), D72.1 (K), U2.1 (CA9)
CB1: D73.1 (K), D74.2 (A), D75.2 (A), D76.2 (A), D77.2 (A), D78.2 (A), D79.2 (A), D80.2 (A), D81.2 (A), D82.1 (K), D91.1 (K), D100.1 (K), D109.1 (K), D118.1 (K), D127.1 (K), D136.1 (K), U2.7 (CB1)
CB2: D73.2 (A), D74.1 (K), D83.1 (K), D84.2 (A), D85.2 (A), D86.2 (A), D87.2 (A), D88.2 (A), D89.2 (A), D90.2 (A), D92.1 (K), D101.1 (K), D110.1 (K), D119.1 (K), D128.1 (K), D137.1 (K), U2.8 (CB2)
CB3: D75.1 (K), D82.2 (A), D83.2 (A), D84.1 (K), D93.1 (K), D94.2 (A), D95.2 (A), D96.2 (A), D97.2 (A), D98.2 (A), D99.2 (A), D102.1 (K), D111.1 (K), D120.1 (K), D129.1 (K), D138.1 (K), U2.9 (CB3)
CB4: D76.1 (K), D85.1 (K), D91.2 (A), D92.2 (A), D93.2 (A), D94.1 (K), D103.1 (K), D104.2 (A), D105.2 (A), D106.2 (A), D107.2 (A), D108.2 (A), D112.1 (K), D121.1 (K), D130.1 (K), D139.1 (K), U2.10 (CB4)
CB5: D77.1 (K), D86.1 (K), D95.1 (K), D100.2 (A), D101.2 (A), D102.2 (A), D103.2 (A), D104.1 (K), D113.1 (K), D114.2 (A), D115.2 (A), D116.2 (A), D117.2 (A), D122.1 (K), D131.1 (K), D140.1 (K), U2.11 (CB5)
CB6: D78.1 (K), D87.1 (K), D96.1 (K), D105.1 (K), D109.2 (A), D110.2 (A), D111.2 (A), D112.2 (A), D113.2 (A), D114.1 (K), D123.1 (K), D124.2 (A), D125.2 (A), D126.2 (A), D132.1 (K), D141.1 (K), U2.12 (CB6)
CB7: D79.1 (K), D88.1 (K), D97.1 (K), D106.1 (K), D115.1 (K), D118.2 (A), D119.2 (A), D120.2 (A), D121.2 (A), D122.2 (A), D123.2 (A), D124.1 (K), D133.1 (K), D134.2 (A), D135.2 (A), D142.1 (K), U2.13 (CB7)
CB8: D80.1 (K), D89.1 (K), D98.1 (K), D107.1 (K), D116.1 (K), D125.1 (K), D127.2 (A), D128.2 (A), D129.2 (A), D130.2 (A), D131.2 (A), D132.2 (A), D133.2 (A), D134.1 (K), D143.1 (K), D144.2 (A), U2.14 (CB8)
CB9: D81.1 (K), D90.1 (K), D99.1 (K), D108.1 (K), D117.1 (K), D126.1 (K), D135.1 (K), D136.2 (A), D137.2 (A), D138.2 (A), D139.2 (A), D140.2 (A), D141.2 (A), D142.2 (A), D143.2 (A), D144.1 (K), U2.15 (CB9)
D+: D146.1 (A1), J1.A6 (D+), J1.B6 (D+), R1.2
D-: D147.1 (A1), J1.A7 (D-), J1.B7 (D-), R2.2
DIG0: R9.2, U3.2 (DIG0), U5.3 (CC), U5.8 (CC)
DIG1: R10.2, U3.3 (DIG1), U6.3 (CC), U6.8 (CC)
DIG2: R11.2, U3.4 (DIG2), U7.3 (CC), U7.8 (CC)
GND: BT1.2 (-), BT2.2 (-), BZ1.2 (-), C1.2, C2.1, C3.1, C4.2, C5.2, C6.2, C7.2, C8.2, C9.2, C10.2, C11.2, C12.2, C13.2, C14.2, C15.2, C16.2, D146.2 (A2), D147.2 (A2), D148.2 (A2), J1.A1 (GND), J1.A12 (GND), J1.B1 (GND), J1.B12 (GND), J1.S1 (SHIELD), J2.1, J3.6 (GND), R7.2, R14.2, R15.2, SW1.2 (B), SW1.3 (GND), SW2.2 (B), SW2.3 (GND), SW3.2 (B), SW3.3 (GND), SW4.2 (B), SW4.3 (GND), SW5.2 (B), SW5.3 (GND), SW6.2 (B), SW6.3 (GND), SW7.2 (B), SW7.3 (GND), SW8.2 (B), SW8.3 (GND), SW9.2 (B), SW9.3 (GND), SW10.2 (B), SW10.3 (GND), SW11.2 (B), SW11.3 (GND), SW12.2 (B), SW12.3 (GND), SW13.2, U1.5 (UGND), U1.15 (GND), U1.23 (GND), U1.35 (GND), U1.43 (GND), U2.5 (GND), U2.18 (AD), U3.6 (GND), U4.2 (GND), X1.2 (GND)
MISO: J3.1 (MISO), U1.11 (PB3)
MOSI: J3.4 (MOSI), U1.10 (PB2)
unnamed: BZ1.1 (+), R16.1
unnamed: D145.2 (A), SW14.2 (B)
unnamed: J1.A5 (CC1), R14.1
unnamed: J1.B5 (CC2), R15.1
unnamed: C3.2, U1.42 (AREF)
unnamed: C1.1, U1.17 (XTAL1), X1.3 (OUT)
unnamed: C2.2, U1.16 (XTAL2), X1.1 (Tri-State)
unnamed: C9.1, U2.16 (C_FILT)
unnamed: C8.1, U2.17 (IN)
unnamed: R7.1, U2.6 (R_EXT)
unnamed: R5.2, U2.4 (~INTB)
unnamed: R6.2, U2.3 (~SDB)
unnamed: R8.1, U3.13 (ISET)
RST: J3.5 (~RST), R3.1, SW13.1, U1.13 (~RESET)
SCK: J3.3 (SCK), U1.9 (PB1)
SCL: J2.4, R13.2, U1.18 (PD0), U2.20 (SCL), U3.14 (SCL)
SDA: J2.3, R12.2, U1.19 (PD1), U2.19 (SDA), U3.1 (SDA)
SEGA: U3.15 (SEGA), U5.7 (A), U6.7 (A), U7.7 (A)
SEGB: U3.17 (SEGB), U5.6 (B), U6.6 (B), U7.6 (B)
SEGC: U3.20 (SEGC), U5.4 (C), U6.4 (C), U7.4 (C)
SEGD: U3.23 (SEGD), U5.2 (D), U6.2 (D), U7.2 (D)
SEGDP: U3.22 (SEGDP), U5.5 (DP), U6.5 (DP), U7.5 (DP)
SEGE: U3.21 (SEGE), U5.1 (E), U6.1 (E), U7.1 (E)
SEGF: U3.16 (SEGF), U5.9 (F), U6.9 (F), U7.9 (F)
SEGG: U3.18 (SEGG), U5.10 (G), U6.10 (G), U7.10 (G)
SW1: SW1.1 (A), U1.30 (PB6)
SW2: SW2.1 (A), U1.12 (PB7)
SW3: SW3.1 (A), U1.31 (PC6)
SW4: SW4.1 (A), U1.32 (PC7)
SW5: SW5.1 (A), U1.25 (PD4)
SW6: R4.2, SW6.1 (A), U1.33 (~HWB/PE2)
SW7: SW7.1 (A), U1.26 (PD6)
SW8: SW8.1 (A), U1.27 (PD7)
SW9: SW9.1 (A), U1.39 (PF4)
SW10: SW10.1 (A), U1.40 (PF1)
SW11: SW11.1 (A), U1.41 (PF0)
SW12: SW12.1 (A), U1.1 (PE6)
VBAT: BT1.1 (+), BT2.1 (+), SW14.1 (A)
VBUS: D148.1 (A1), F1.1, J1.A4 (VBUS), J1.A9 (VBUS), J1.B4 (VBUS), J1.B9 (VBUS), U1.7 (VBUS)
VIN: C12.1, C13.1, D145.1 (K), F1.2, U4.1 (IN), U4.3 (EN)

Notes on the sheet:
Design Flaw Note: Clock uses CMOS oscillator (XO) instead of crystal (XTAL). Tri-state pin must be floating or high, and caps are not needed. Set fuse to external clock to keep XTAL2 at high impedance.
Design Note: New alkaline CR2032 (3V) brown out, but rechargeable lithium CR2032 (3.7V) work fine. MIC5219 supports up to 12V, so batteries can/should be in series for stability.
Pull-ups values roughly calculated for <400 kHz I2C bus speed. Will need <~5k for >400 kHz.
LED "Matrix"
Design Note: Put more thought and review into LED numbers before layout. These aren't even in order.
Bus Stuff
Power
MCU
Buzzer
Connectors
Switches
so lonely
Overloading one button for use as bootloader button at boot
7 Segment Display
Schottky diodes are for ESD protection for USB bus.

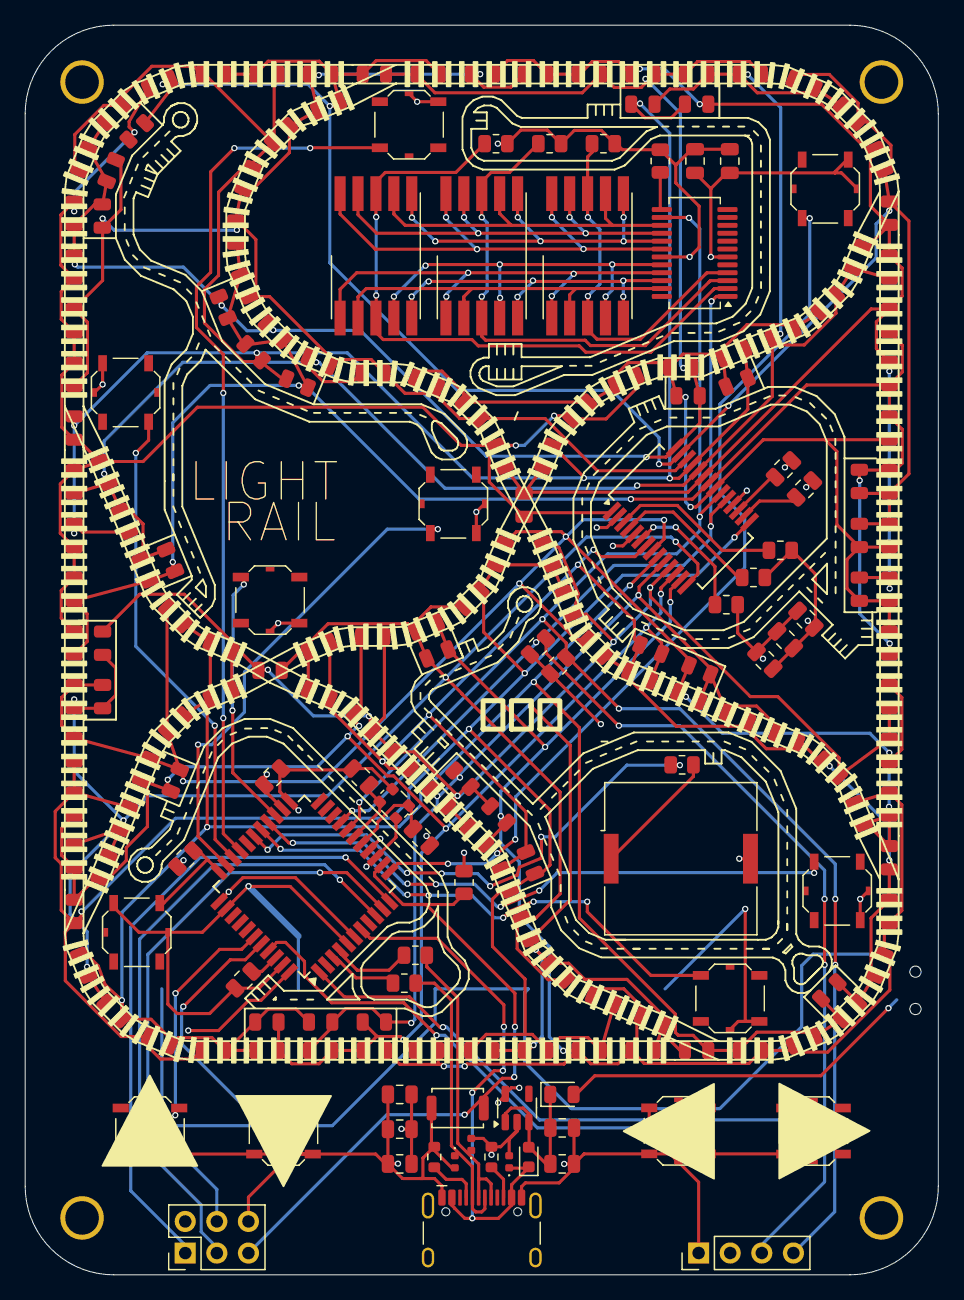
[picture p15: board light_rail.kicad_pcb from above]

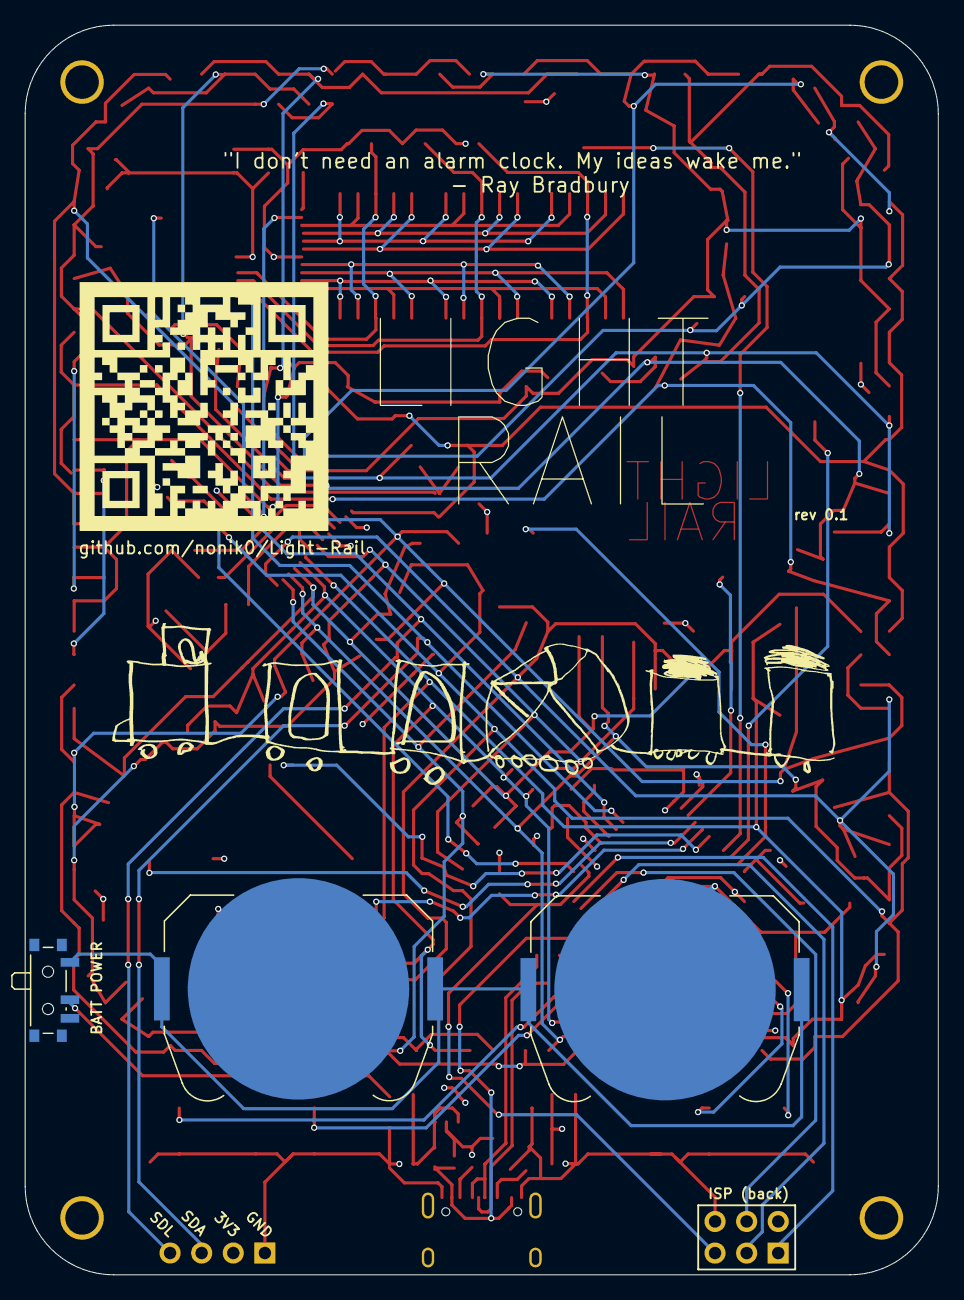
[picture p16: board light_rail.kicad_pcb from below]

Board: 4 copper layers, 73.4 x 100.5 mm, 213 parts (3 on the bottom side), 70 nets.

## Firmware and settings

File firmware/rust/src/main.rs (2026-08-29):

#![no_std]
#![no_main]
#![feature(abi_avr_interrupt)]
#![feature(const_trait_impl)]
#![feature(panic_info_message)]
#![feature(type_alias_impl_trait)]

// TODO: can print to digits before panic halting
#[cfg(not(feature = "panic_to_digits"))]
#[macro_export]
macro_rules! panic_with_error {
    ($error_code:expr) => {
        panic!()
    };
}

use atmega_hal::adc;
use core::cell::RefCell;
use embedded_hal::delay::DelayNs;
use embedded_hal_bus::i2c::{self};
#[cfg(not(feature = "panic_to_digits"))]
use panic_halt as _;

type Adc = atmega_hal::adc::Adc<CoreClock>;
#[cfg(feature = "atmega32u4")]
type CoreClock = atmega_hal::clock::MHz8;
#[cfg(feature = "atmega328p")]
type CoreClock = atmega_hal::clock::MHz16;
type Delay = atmega_hal::delay::Delay<CoreClock>;
type Eeprom = atmega_hal::eeprom::Eeprom;
type I2c = atmega_hal::i2c::I2c<CoreClock>;

mod cargo;
mod game;
mod game_settings;
mod game_state;
mod input;
mod location;
mod modes;
#[cfg(feature = "panic_to_digits")]
mod panic;
mod platform;
mod random;
mod switch;
#[cfg_attr(not(feature = "atmega32u4"), path = "notone.rs")]
mod tone;
mod train;

const NUM_BUTTONS: usize = 12;
const NUM_DIGITS: u8 = 3;
const DIGITS_I2C_ADDR: u8 = as1115::DEFAULT_ADDRESS;
const LEDS_I2C_ADDR: u8 = is31fl3731::DEFAULT_ADDRESS;

#[avr_device::entry]
fn main() -> ! {
    let dp = atmega_hal::Peripherals::take().unwrap();
    let pins = atmega_hal::pins!(dp);
    let mut delay = Delay::new();
    let i2c = I2c::new(
        dp.TWI,
        #[cfg(feature = "atmega32u4")]
        pins.pd1.into_pull_up_input(),
        #[cfg(feature = "atmega328p")]
        pins.pc4.into_pull_up_input(),
        #[cfg(feature = "atmega32u4")]
        pins.pd0.into_pull_up_input(),
        #[cfg(feature = "atmega328p")]
        pins.pc5.into_pull_up_input(),
        400_000,
    );
    let i2c_ref_cell = RefCell::new(i2c);

    #[cfg(feature = "atmega32u4")]
    let board_buzzer = tone::TimerTone::new(dp.TC3, pins.pb4.into_output().downgrade());
    #[cfg(feature = "atmega328p")]
    let board_buzzer = tone::TimerTone::new();

    let eeprom = Eeprom::new(dp.EEPROM);
    let settings = game_settings::GameSettings::new(eeprom);

    let mut board_digits =
        as1115::AS1115::new_with_addr(i2c::RefCellDevice::new(&i2c_ref_cell), DIGITS_I2C_ADDR);
    board_digits.init(settings.digit_brightness_level()).ok();
    board_digits.clear().ok();

    #[cfg(feature = "atmega32u4")]
    let input_pins = [
        pins.pb6.into_pull_up_input().downgrade(),
        pins.pb7.into_pull_up_input().downgrade(),
        pins.pc6.into_pull_up_input().downgrade(),
        pins.pc7.into_pull_up_input().downgrade(),
        pins.pd4.into_pull_up_input().downgrade(),
        pins.pe2.into_pull_up_input().downgrade(),
        pins.pd6.into_pull_up_input().downgrade(),
        pins.pd7.into_pull_up_input().downgrade(),
        pins.pf4.into_pull_up_input().downgrade(),
        pins.pf1.into_pull_up_input().downgrade(),
        pins.pf0.into_pull_up_input().downgrade(),
        pins.pe6.into_pull_up_input().downgrade(),
    ];
    #[cfg(feature = "atmega328p")]
    let input_pins = [
        pins.pd0.into_pull_up_input().downgrade(),
        pins.pd1.into_pull_up_input().downgrade(),
        pins.pd2.into_pull_up_input().downgrade(),
        pins.pd3.into_pull_up_input().downgrade(),
        pins.pd4.into_pull_up_input().downgrade(),
        pins.pd5.into_pull_up_input().downgrade(),
        pins.pd6.into_pull_up_input().downgrade(),
        pins.pd7.into_pull_up_input().downgrade(),
        pins.pb0.into_pull_up_input().downgrade(),
        pins.pb1.into_pull_up_input().downgrade(),
        pins.pb2.into_pull_up_input().downgrade(),
        pins.pb3.into_pull_up_input().downgrade(),
    ];
    let board_input = input::BoardInput::new(input_pins);

    let mut board_leds =
        is31fl3731::IS31FL3731::new(i2c::RefCellDevice::new(&i2c_ref_cell), LEDS_I2C_ADDR);
    board_leds.setup_blocking(&mut delay).unwrap(); // TODO: why does OK hang???
    board_leds.clear_blocking().ok();

    // generate random seed from ADC temperature sensor
    let mut adc = Adc::new(dp.ADC, Default::default());
    let mut seed: u32 = 0;
    for i in 0..8 {
        // using 4 LSB bits x 8 readings for 32 bit seed
        let reading = adc.read_blocking(&adc::channel::Temperature);
        let lsb = (reading & 0xF) as u32;
        seed |= lsb << (i * 4);
    }
    random::Rand::seed(seed);

    let cars = [train::Car::default(); game_state::MAX_CARS];
    let mut game = game::Game::new(
        board_buzzer,
        board_digits,
        board_input,
        board_leds,
        cars,
        settings,
    );
    game.restart();

    loop {
        game.tick();
        delay.delay_ms(game.base_delay());
    }
}

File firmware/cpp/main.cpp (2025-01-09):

#include <Arduino.h>

#include "common.h"
#include "game.h"

// singleton instance of Game manages all game state and board hardware
Game &game = Game::getInstance();

void setup()
{
  Serial.begin(9600);
  log("Starting setup...");

  // disable ADC to save power
  ADCSRA = 0;

  game.setup();
  // game.modeSelect();

  log("Setup complete!");
}

void loop()
{
  if (game.isOver())
  {
    // game.modeSelect();
    game.restart(); 
  }

  game.tick();

  delay(30); // TODO: configurable to control overall game speed
}

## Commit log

2024-11-15 changes for fab
    [Light_Rail_BOM.xlsx, light_rail.kicad_pcb]
2024-11-20 fab updates 2
    [light_rail.kicad_pcb, light_rail.kicad_sch]
2024-11-30 post-prod schematic fix, should be no change
    [light_rail.kicad_pcb, light_rail.kicad_sch]
2024-12-14 BoM fix
    [Light_Rail_BOM.xlsx, light_rail.kicad_pcb]
2024-12-15 basic working prototype
2025-01-09 testing board
2025-01-09 untested full graph, switch tests
2025-01-09 BOM fix for RST switch
    [Light_Rail_BOM.xlsx]
2025-01-14 working is31 driver in rust
2025-01-15 as1115 driver
2025-01-15 use is31 github driver
2025-01-16 some progress on timer
2025-01-28 working tone with timer1
2025-01-30 change to timer3
2025-02-02 added design comments to schematic, added schematic image
    [light_rail.kicad_pcb, light_rail.kicad_sch]
2025-02-02 adding more images and moving around stuff
    [Light_Rail_BOM.xlsx, light_rail.kicad_pcb, pcbway_quote.xls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]
2025-05-12 no panics, rand issues still?
    [game.rs, main.rs, panic.rs]
2025-05-16 switch progress, try out panic error_code
    [common.rs, game.rs, main.rs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]
2025-05-16 more switch progress
2025-05-18 switch indicator test
2025-05-18 working switches/crosses
2025-05-19 defining game flow more
2025-05-20 switch improvements
2025-06-03 refactoring entityupdates to ledupdates
2025-06-16 fixes, let snake get stuck for nwo
    [main.rs]
2025-06-17 use decimals for timer indicator
2025-06-17 juggle mode, issue with modes
    [game.rs]
2026-08-29 wire up autostop
